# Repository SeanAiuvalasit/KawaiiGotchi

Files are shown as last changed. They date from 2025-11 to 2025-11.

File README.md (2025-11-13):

## AI usage
This project was programmed with the aid of ChatGPT. Specifically, all of the Arduino code for the ESP32.

## How it works

The Kawaiigotchi is powered via a USB connection from a laptop that outputs 5V. When the ESP32 turns on, there should be no weight placed on the scale as the ESP32 tares the load cell. After the display has shown 0 or -0.1 g, the user can place the water bottle on the plate. The amount of time it takes for the Kawaiigotchi to remind the user to drink water can be adjusted by changing the delay in 
[
bool showHint = (millis() - presentSinceMs >= 20000UL);
]. 
The amount of weight change  that qualifies as enough water can be adjusted by changing the constant in the code. 
[
const float ENOUGH_PER_SIP_ML = 100.0f;
]

## Inspiration

NYU Students made a vape pen with a Tamagotchi that dies if the user stops vaping. We loved the idea of a pet tamagotchi device serving as motivation but, for a healthier cause. After long study sessions in the Student Computing Center where we left with dehydration-induced headaches of our own making, we realized what our solution would be… We decided to design a desk-pal for your water bottle where a tamagotchi reminds you to stay hydrated during study sessions.

 ## What it does

The Kawaiigotchi takes in weight inputs from the Load Cell to detect the presence of a water bottle. After a programmed period of time, the screen text changes to remind the user to drink water. It detects when the bottle has been lifted and waits for the user to set the water bottle down. It then compares the weight of the bottle from before and after it was picked up by the user. If the difference surpasses a threshold, a happy Kawaiigotchi is displayed on the screen, otherwise the Kawaiigotchi will alert the user that they did not drink enough water. Both times it will display the change in weight detected by the load cell on the OLED display.

## How we built it

The first step was developing an idea for our problem. Next we assessed the components needed to build the device that reminds students to drink water. We tested different parts to understand how they would operate in our use case. This led to us replacing a force sensitive resistor with a load cell for weight measurement for increase reliability. After understanding how the individual components worked, we soldered connections for the HX711 load cell amplifier IC and started 3D modelling the scale in OnShape. We used a Bambu Lab A1 Mini with pink PLA filament to print the model of the scale. Then we wired the components on a breadboard and started writing the finalized code. We used a ESP32 Devkit, Adafruit SSD1306 OLED display, 5 kg load cell, and HX711 load cell amplifier to make our device.

## Challenges we ran into

Initially we planned on using a force sensitive resistor to detect the presence of the water bottle and measure a change in the weight of the water bottle. Through testing of the force sensitive resistor, we realized that the FSR resistor was incapable of producing an accurate reading and that the reading would change over the course of the resistor being on due to heat increasing the resistance of the resistor decreased.
We initially planned to display an image of a cat according to the water levels drinking. Unfortunately, we were not able to get the code working within the time frame. In replacement, we stayed with the text reminders. The CAD design for the breadboard holder was not deep enough to hold all the electronic components and wires. This did not cause any technical issues, only the final display was not as clean as intended. Another unseen issue ran into from CAD design was the screw to secure the water bottle scale plate to the load cell. The product does work fine despite the protruding screw, but a water bottle cannot be placed on the center of the device. Counterboring the screws would have led to a more flawless product.

## Accomplishments that we're proud of

We’re proud that we finished with a complete product and that no parts were harmed in the process of creating our Kawaiigotchi. We’re also proud that the Kawaiigotchi is fully functional and that it can even be expanded on in the future, and we are also proud of how we were able to use parts that we’ve never used before and make something out of it.

## What we learned

We learned that your first CAD design won’t always be perfect, and that most of the time it will be faulty in some ways. We learned more about setting up the Arduino IDE and the coding language that it uses. This project was our first time utilizing an OLED display. Although we did not use it to the full extent imagined, we still learned how to display information to the screen. 

## What's next for Kawaiigotchi

If we were going to keep the Kawaiigotchi together, we would first improve the CAD design so all of the parts fit inside the Kawaiigotchi. We could also possibly add more faces and states for the display based on different inputs from the user, and we’d also change to a larger display so that we can print full images of silly faces. It could also become a pomodoro timer that lets the user focus by replacing a phone with a desk-pal for timing. Unfortunately, we have to disassemble our Kawaiigotchi and return all of the parts that we borrowed.

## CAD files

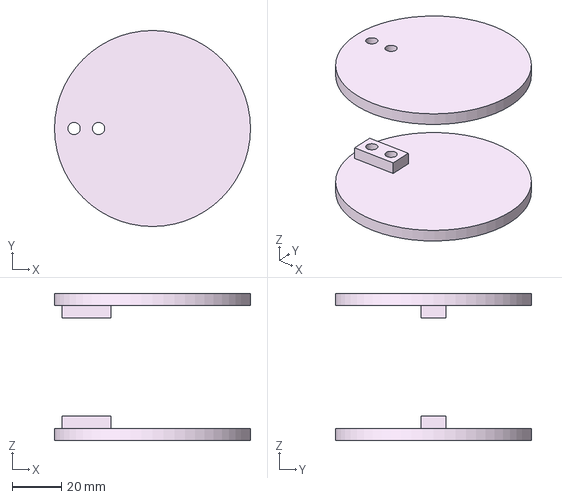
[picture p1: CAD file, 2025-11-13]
Plates.step
80.0 x 80.0 x 60.0 mm

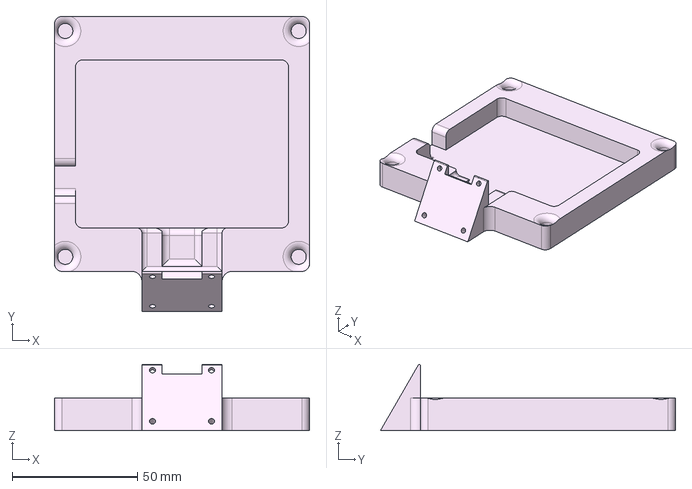
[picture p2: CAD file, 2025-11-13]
Base.step
101.6 x 117.6 x 26.3 mm

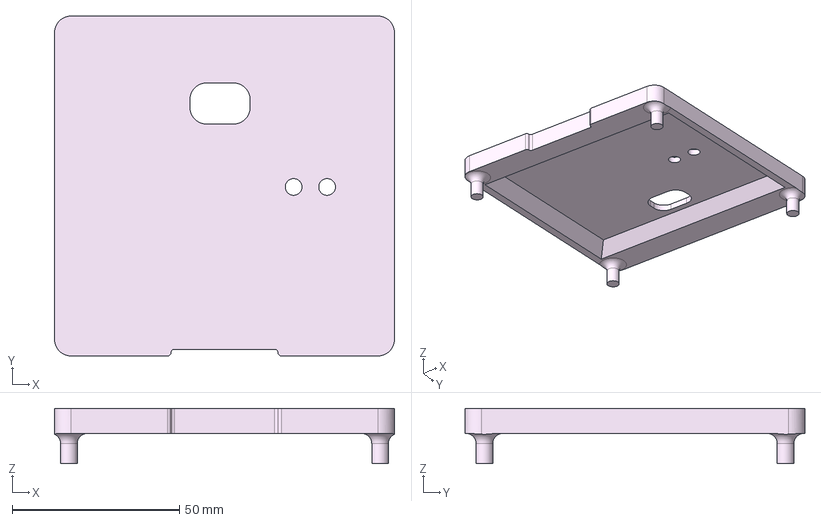
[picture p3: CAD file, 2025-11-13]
Lid.step
101.6 x 101.6 x 16.5 mm

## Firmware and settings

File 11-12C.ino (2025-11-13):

#include <Arduino.h>
#include "HX711.h"
#include <Wire.h>
#include <Adafruit_GFX.h>
#include <Adafruit_SSD1306.h>


// --------- Pins ----------
#define DOUT_PIN    33
#define SCK_PIN     14
#define BUZZER_PIN  27
#define SDA_PIN     22
#define SCL_PIN     21


// --------- Display ----------
#define SCREEN_WIDTH 128
#define SCREEN_HEIGHT 64
Adafruit_SSD1306 display(SCREEN_WIDTH, SCREEN_HEIGHT, &Wire, -1);


// --------- Scale ----------
HX711 scale;
float CAL_FACTOR = 2280.0f;     // adjust after calibration


// --------- Thresholds (grams/mL) ----------
const float THRESHOLD_ON   = 15.0f;     // enter "present" when >= this
const float THRESHOLD_OFF  = 8.0f;      // leave "present" when <= this
const float MIN_SIP        = 5.0f;      // minimum delta to count as a sip
const float STABLE_EPS     = 2.0f;      // small deadband for “stable”
const unsigned long DROP_DEBOUNCE_MS = 1500; // drop must persist this long


// --------- “Enough?” per-sip rule ----------
const float ENOUGH_PER_SIP_ML = 100.0f; // adjust your per-sip target


// --------- State Machine ----------
enum State { NO_BOTTLE, BOTTLE_PRESENT };
State state = NO_BOTTLE;


// --------- Baselines / detection helpers ----------
float presentMaxBaseline = 0.0f;  // max stable level while present
float lastStableLevel    = 0.0f;  // last accepted plateau


bool  dropArmed           = false;  // tracking a candidate drop
float dropStartLevel      = 0.0f;
unsigned long dropStartMs = 0;


// remove/return decision uses this
float pendingBeforeRemoval = 0.0f;


// timing for “waiting for sips…” hint
unsigned long presentSinceMs = 0;  // set when bottle becomes present


// --------- Bitmaps (converted from your files, 64x64, 1-bit) ----------
#define KAWAII_W 64
#define KAWAII_H 64


// Happy cat 64x64 (from: epd_bitmap_ (1).bin), 1-bit, row-packed (LSB first)
const unsigned char PROGMEM kawaii_happy[] = {
  0x00, 0x00, 0x00, 0x00, 0x00, 0x00, 0x00, 0x00, 0x00, 0x00, 0x00, 0x00, 0x00, 0x00, 0x00, 0x00,
  0x00, 0x00, 0x00, 0x00, 0x00, 0x00, 0x00, 0x00, 0x00, 0x00, 0x00, 0x00, 0x00, 0x00, 0x00, 0x00,
  0x00, 0x00, 0x00, 0x00, 0x00, 0x00, 0x00, 0x00, 0x00, 0x00, 0x00, 0x00, 0x00, 0x00, 0x00, 0x00,
  0x00, 0x00, 0x00, 0x00, 0x00, 0x00, 0x00, 0x00, 0x00, 0x00, 0x00, 0x00, 0x00, 0x00, 0x00, 0x00,
  0x1E, 0x00, 0x00, 0x00, 0x00, 0x00, 0x00, 0x00, 0x00, 0x00, 0x00, 0x00, 0x00, 0x00, 0x00, 0x78,
  0xFF, 0x03, 0x00, 0x00, 0x00, 0x00, 0x00, 0x00, 0x00, 0x00, 0x00, 0x00, 0x00, 0x00, 0xC0, 0xFF,
  0xFF, 0x3F, 0x00, 0x00, 0x00, 0x00, 0x00, 0x00, 0x00, 0x00, 0x00, 0x00, 0x00, 0xF0, 0xFF, 0xFF,
  0xFF, 0xFF, 0x03, 0x00, 0x00, 0x00, 0x00, 0x00, 0x00, 0x00, 0x00, 0xC0, 0xFF, 0xFF, 0xFF, 0xFF,
  0xFF, 0xFF, 0x1F, 0x00, 0x00, 0x00, 0x00, 0x00, 0x00, 0x00, 0x80, 0xFF, 0xDF, 0xFB, 0xFF, 0xFF,
  0xFF, 0xDF, 0xFF, 0x01, 0x00, 0x00, 0x00, 0x00, 0x00, 0x80, 0xFF, 0x6F, 0xB6, 0xDB, 0xFF, 0xFF,
  0xFF, 0xAD, 0xFD, 0xFF, 0x00, 0x00, 0x00, 0x00, 0x80, 0xFF, 0x7F, 0xB3, 0x6D, 0xB7, 0xDB, 0xFF,
  0x6D, 0xDB, 0xEC, 0xFF, 0x01, 0x00, 0x00, 0x80, 0xFF, 0xBF, 0x59, 0x6F, 0xB6, 0xDB, 0x6E, 0xDB,
  0xB6, 0xB5, 0xF6, 0xFF, 0x01, 0x00, 0x80, 0xFF, 0xDF, 0xCD, 0xDA, 0xB6, 0x6D, 0xDB, 0xB6, 0xB5,
  0x6D, 0xBB, 0xFD, 0x7F, 0x00, 0x80, 0xFF, 0xDF, 0xCC, 0xB6, 0x6D, 0xDB, 0xB6, 0x6D, 0x6B, 0xDB,
  0xB6, 0x6D, 0xFB, 0x7F, 0x80, 0xFF, 0xDF, 0xCC, 0xB6, 0x6D, 0xDB, 0xB6, 0x6D, 0x6B, 0xDB, 0xB6,
  0x6D, 0xBB, 0xFD, 0x7F, 0x80, 0xFF, 0xDF, 0xCD, 0xDA, 0xB6, 0x6D, 0xDB, 0xB6, 0xB5, 0x6D, 0xBB,
  0xF6, 0xFE, 0x7F, 0x80, 0xFF, 0x7F, 0xB3, 0x6D, 0xB7, 0xDB, 0xFF, 0x6D, 0xDB, 0xEC, 0xFF, 0x7F,
  0x80, 0xFF, 0x6F, 0xB6, 0xDB, 0xFF, 0xFF, 0xFF, 0xAD, 0xFD, 0xFF, 0x7F, 0x80, 0xFF, 0xDF, 0xFB,
  0xFF, 0xFF, 0xFF, 0xDF, 0xFF, 0x7D, 0x7F, 0x80, 0xFF, 0xFF, 0xFF, 0xFF, 0xFF, 0x03, 0x00, 0x00,
  0x80, 0xFF, 0x1F, 0x7F, 0x80, 0xFF, 0xFF, 0xFF, 0xFF, 0x03, 0x00, 0x00, 0x80, 0x7F, 0x00, 0x7E,
  0x80, 0x3F, 0xFC, 0xFF, 0xE1, 0x03, 0x18, 0x00, 0x78, 0x00, 0x3E, 0x80, 0x0F, 0xF0, 0x7F, 0x80,
  0x03, 0x18, 0x00, 0x60, 0x00, 0x18, 0x80, 0x07, 0x80, 0x1F, 0x00, 0x00, 0x03, 0x18, 0x00, 0x60,
  0x00, 0x18, 0x80, 0x07, 0x80, 0x1F, 0x00, 0x00, 0x03, 0x18, 0x00, 0x60, 0x00, 0x18, 0x80, 0x07,
  0x80, 0x1F, 0x00, 0x00, 0x03, 0x18, 0x00, 0x60, 0x00, 0x18, 0x80, 0x0F, 0xF0, 0x7F, 0x80, 0x03,
  0x18, 0x00, 0x60, 0x00, 0x18, 0x80, 0x3F, 0xFC, 0xFF, 0xE1, 0x03, 0x18, 0x00, 0x78, 0x00, 0x3E,
  0x80, 0x7F, 0x00, 0x7E, 0x80, 0xFF, 0x1F, 0x7F, 0x80, 0xFF, 0x03, 0x00, 0x80, 0xFF, 0xFF, 0xFF,
  0xFF, 0x7F, 0x80, 0xFF, 0x7D, 0x7F, 0x80, 0xFF, 0x6F, 0xB6, 0xDB, 0xFF, 0xFF, 0xFF, 0xAD, 0xFD,
  0xFF, 0x7F, 0x80, 0xFF, 0x7F, 0xB3, 0x6D, 0xB7, 0xDB, 0xFF, 0x6D, 0xDB, 0xEC, 0xFF, 0x7F, 0x80,
  0xFF, 0xDF, 0xCD, 0xDA, 0xB6, 0x6D, 0xDB, 0xB6, 0xB5, 0x6D, 0xBB, 0xF6, 0xFE, 0x7F, 0x80, 0xFF,
  0xDF, 0xCC, 0xB6, 0x6D, 0xDB, 0xB6, 0x6D, 0x6B, 0xDB, 0xB6, 0x6D, 0xBB, 0xFD, 0x7F, 0x80, 0xFF,
  0xDF, 0xCC, 0xB6, 0x6D, 0xDB, 0xB6, 0x6D, 0x6B, 0xDB, 0xB6, 0x6D, 0xBB, 0xFD, 0x7F, 0x00, 0x80,
  0xFF, 0xDF, 0xCD, 0xDA, 0xB6, 0x6D, 0xDB, 0xB6, 0xB5, 0x6D, 0xBB, 0xFD, 0x7F, 0x00, 0x80, 0xFF,
  0x7F, 0xB3, 0x6D, 0xB7, 0xDB, 0xFF, 0x6D, 0xDB, 0xEC, 0xFF, 0x7F, 0x00, 0x80, 0xFF, 0x6F, 0xB6,
  0xDB, 0xFF, 0xFF, 0xFF, 0xAD, 0xFD, 0xFF, 0x7F, 0x00, 0x80, 0xFF, 0xDF, 0xFB, 0xFF, 0xFF, 0xFF,
  0xDF, 0xFF, 0x7D, 0x7F, 0x00, 0x80, 0xFF, 0xFF, 0xFF, 0xFF, 0xFF, 0x03, 0x00, 0x00, 0x80, 0xFF,
  0x1F, 0x7F, 0x00, 0xF0, 0xFF, 0xFF, 0x0F, 0x00, 0x80, 0x3F, 0xFE, 0x3F, 0x00, 0xC0, 0xFF, 0xFF,
  0x03, 0x00, 0x80, 0x07, 0xF0, 0x07, 0x00, 0x00, 0xFE, 0x7F, 0x00, 0x00, 0x80, 0x07, 0xF0, 0x07,
  0x00, 0x00, 0xFE, 0x7F, 0x00, 0x00, 0x80, 0x07, 0xF0, 0x07, 0x00, 0xC0, 0xFF, 0xFF, 0x03, 0x00,
  0x80, 0x3F, 0xFE, 0x3F, 0x00, 0xF0, 0xFF, 0xFF, 0x0F, 0x00, 0x80, 0xFF, 0x1F, 0x7F, 0x00, 0xFC,
  0xFF, 0xFF, 0x3F, 0x00
};


// Disappointed face 64x64 (from: epd_bitmap_ (2).bin), 1-bit, row-packed (LSB first)
const unsigned char PROGMEM kawaii_disappointed[] = {
  0x00, 0x00, 0x00, 0x00, 0x00, 0x00, 0x00, 0x00, 0x00, 0x00, 0x00, 0x00, 0x00, 0x00, 0x00, 0x00,
  0x1F, 0x00, 0x00, 0x00, 0x00, 0x00, 0x00, 0x00, 0x00, 0x00, 0x00, 0x00, 0x00, 0x00, 0x80, 0xF7,
  0xFF, 0x01, 0x00, 0x00, 0x00, 0x00, 0x00, 0x00, 0x00, 0x00, 0x00, 0x00, 0x00, 0xF0, 0x3F, 0xFF,
  0xFF, 0x7F, 0x00, 0x00, 0x00, 0x00, 0x00, 0x00, 0x00, 0x00, 0xC0, 0xBF, 0xC9, 0xBE, 0xFF, 0xFE,
  0x0F, 0x00, 0x00, 0x00, 0x00, 0x00, 0x00, 0x80, 0x7F, 0x93, 0x24, 0x69, 0xDE, 0xF7, 0xFD, 0x01,
  0x00, 0x00, 0x00, 0x00, 0x80, 0x7F, 0x93, 0x24, 0x49, 0x92, 0xB4, 0xDE, 0xFB, 0x03, 0x00, 0x00,
  0x00, 0x80, 0x3F, 0x49, 0x92, 0x24, 0x49, 0x92, 0xA4, 0xF5, 0xFE, 0x07, 0x00, 0x00, 0x80, 0x3F,
  0x49, 0x92, 0x24, 0x49, 0x92, 0x24, 0x49, 0xEA, 0xFD, 0x0F, 0x00, 0x00, 0x80, 0x1F, 0x49, 0x92,
  0x24, 0x49, 0x92, 0x24, 0x49, 0x92, 0xF4, 0xFF, 0x1F, 0x00, 0x00, 0xC0, 0x8F, 0x24, 0x49, 0x92,
  0x24, 0x49, 0x92, 0x24, 0x49, 0xEA, 0xFF, 0x3F, 0x00, 0x00, 0xE0, 0x47, 0x92, 0x24, 0x49, 0x92,
  0x24, 0x49, 0x92, 0x24, 0x49, 0xFA, 0xFF, 0x7F, 0x00, 0x00, 0xF0, 0x23, 0x49, 0x92, 0x24, 0x49,
  0x92, 0x24, 0x49, 0x92, 0xA4, 0xFD, 0xFF, 0xFF, 0x00, 0x00, 0xF8, 0x91, 0x24, 0x49, 0x92, 0x24,
  0x49, 0x92, 0x24, 0x49, 0xDA, 0xFF, 0xFF, 0xFF, 0x01, 0x00, 0xFC, 0x48, 0x92, 0x24, 0x49, 0x92,
  0x24, 0x49, 0x92, 0xA4, 0xED, 0xFF, 0xFF, 0xFF, 0x03, 0x00, 0x3E, 0x24, 0x49, 0x92, 0x24, 0x49,
  0x92, 0x24, 0x49, 0xD2, 0xFE, 0xFF, 0x7F, 0x7F, 0x07, 0x00, 0x1F, 0x12, 0x49, 0x92, 0x24, 0x49,
  0x92, 0x24, 0x49, 0xFA, 0xF7, 0xFF, 0x6F, 0x2F, 0x0E, 0x80, 0x0F, 0x89, 0x24, 0x49, 0x92, 0x24,
  0x49, 0x92, 0x24, 0x7D, 0xE3, 0xFF, 0xE7, 0xC7, 0x1C, 0xC0, 0x87, 0x44, 0x92, 0x24, 0x49, 0x92,
  0x24, 0x49, 0xD2, 0xBF, 0xC1, 0xFF, 0xF3, 0xC3, 0x39, 0xE0, 0x43, 0x22, 0x49, 0x92, 0x24, 0x49,
  0x92, 0xA4, 0xB4, 0xDF, 0xE0, 0xFF, 0xF9, 0xF1, 0x73, 0xF0, 0x21, 0x11, 0x49, 0x92, 0x24, 0x49,
  0xD2, 0x5E, 0xDA, 0x6F, 0xF0, 0xFF, 0xFC, 0xF8, 0x39, 0xF8, 0x90, 0x88, 0x24, 0x49, 0x92, 0xA4,
  0xB4, 0xD7, 0xF6, 0x37, 0xF8, 0x7F, 0x7E, 0x7C, 0x1E, 0x7C, 0x48, 0x44, 0x92, 0x24, 0x49, 0xDA,
  0x6D, 0x7B, 0x1B, 0x7C, 0x3F, 0x3F, 0x3E, 0x0F, 0x3E, 0x24, 0x22, 0x49, 0x92, 0xB4, 0xD7, 0xF6,
  0x37, 0x7E, 0x9E, 0x9F, 0x9F, 0x07, 0x1F, 0x12, 0x11, 0x49, 0xDA, 0x6D, 0x7B, 0x1B, 0x3F, 0xCF,
  0xCF, 0xCF, 0x03, 0x0F, 0x89, 0x88, 0xA4, 0xBD, 0xB6, 0xBF, 0xF1, 0xF3, 0xFC, 0xFC, 0x3C, 0xF0,
  0x43, 0x44, 0x24, 0xED, 0xB5, 0xFD, 0xCD, 0x9F, 0xE7, 0xE7, 0xE7, 0x81, 0x07, 0x22, 0x22, 0xE9,
  0xB6, 0xBD, 0x8D, 0x9F, 0xE7, 0xE7, 0xE7, 0x81, 0x07, 0x22, 0x22, 0xA9, 0xB7, 0xBD, 0x8D, 0x9F,
  0xE7, 0xE7, 0xE7, 0x81, 0x07, 0x22, 0x22, 0xA9, 0xB7, 0xBD, 0x8D, 0x9F, 0xE7, 0xE7, 0xE7, 0x81,
  0x07, 0x22, 0x22, 0xA9, 0xB7, 0xBD, 0x8D, 0x9F, 0xE7, 0xE7, 0xE7, 0x81, 0x07, 0x22, 0x22, 0xA9,
  0xB7, 0xBD, 0x8D, 0x9F, 0xE7, 0xE7, 0xE7, 0x81, 0x07, 0x22, 0x22, 0xA9, 0xB7, 0xBD, 0x8D, 0x9F,
  0xE7, 0xE7, 0xE7, 0x81, 0x07, 0x22, 0x22, 0xA9, 0xB7, 0xBD, 0x8D, 0x9F, 0xE7, 0xE7, 0xE7, 0x81,
  0x07, 0x22, 0x22, 0xA9, 0xB7, 0xBD, 0x8D, 0x9F, 0xE7, 0xE7, 0xE7, 0x81, 0x0F, 0x11, 0x11, 0x49,
  0xDB, 0x6D, 0x7B, 0x1B, 0x3F, 0xCF, 0xCF, 0xCF, 0x03, 0x1F, 0x12, 0x11, 0x49, 0xB5, 0xD7, 0xF6,
  0x37, 0x7E, 0x9E, 0x9F, 0x9F, 0x07, 0x3E, 0x24, 0x22, 0x49, 0xDA, 0x6D, 0x7B, 0x1B, 0x7C, 0x3F,
  0x3F, 0x3E, 0x0F, 0x7C, 0x48, 0x44, 0x92, 0xB4, 0xD7, 0xF6, 0x37, 0xF8, 0x7F, 0x7E, 0x7C, 0x1E,
  0xF8, 0x90, 0x88, 0x24, 0x69, 0xDA, 0x6F, 0xF0, 0xFF, 0xFC, 0xF8, 0x39, 0xF0, 0x21, 0x11, 0x49,
  0x92, 0xB4, 0xDF, 0xE0, 0xFF, 0xF9, 0xF1, 0x73, 0xE0, 0x43, 0x22, 0x49, 0x92, 0xA4, 0xB4, 0xDF,
  0xC1, 0xFF, 0xF3, 0xC3, 0x39, 0xC0, 0x87, 0x44, 0x92, 0x24, 0x49, 0xDA, 0x6F, 0x83, 0xFF, 0xE7,
  0xC7, 0x1C, 0x80, 0x0F, 0x89, 0x24, 0x49, 0xB2, 0xDF, 0x06, 0xFF, 0xCF, 0x8F, 0x9B, 0x00, 0x1F,
  0x12, 0x49, 0x92, 0x7C, 0xBF, 0x0D, 0xFE, 0x9F, 0x1F, 0x37, 0x01, 0x3E, 0x24, 0x92, 0x24, 0xF9,
  0x7E, 0x1B, 0xFC, 0x3F, 0x3F, 0x6E, 0x02, 0x7C, 0x48, 0x24, 0x49, 0xF2, 0xFD, 0x36, 0xF8, 0x7F,
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
};


// --------- Helpers ----------
void buzz(uint16_t freq, uint16_t durMs) { tone(BUZZER_PIN, freq, durMs); }


void displayLines(const String &l1, const String &l2 = "", const String &l3 = "") {
  display.clearDisplay();
  display.setTextSize(1);
  display.setTextColor(SSD1306_WHITE);


  display.setCursor(0, 0);
  display.println("Kawaiigochi");
  display.drawLine(0, 10, 127, 10, SSD1306_WHITE);


  if (l1.length()) { display.setCursor(0, 18); display.println(l1); }
  if (l2.length()) { display.setCursor(0, 30); display.println(l2); }
  if (l3.length()) { display.setCursor(0, 42); display.println(l3); }


  display.display();
}


// Show weight; optionally include the “Waiting for sips...” hint
void showWeight(float w, bool showWaitingHint) {
  if (showWaitingHint) {
    displayLines(String("Weight: ") + String(w, 1) + " g", "Waiting for sips...");
  } else {
    displayLines(String("Weight: ") + String(w, 1) + " g");
  }
}


// Smoothed reading (grams ≈ mL)
float readWeight() { return scale.get_units(10); }


// When a drink is detected
void onDrink(float amount) {
  bool enough = (amount >= ENOUGH_PER_SIP_ML);


  display.clearDisplay();
  // Center a 64x64 image on a 128x64 screen -> x = 32, y = 0
  if (enough) {
    display.drawBitmap(32, 0, kawaii_happy, KAWAII_W, KAWAII_H, SSD1306_WHITE);
  } else {
    display.drawBitmap(32, 0, kawaii_disappointed, KAWAII_W, KAWAII_H, SSD1306_WHITE);
  }


  // Text near bottom
  display.setTextSize(1);
  display.setTextColor(SSD1306_WHITE);
  display.setCursor(0, 52);
  display.print("Drank: ");
  display.print(amount, 0);
  display.print(" mL  ");
  display.print("Enough: ");
  display.print(enough ? "Yes" : "No");
  display.display();


  buzz(enough ? 1200 : 800, enough ? 150 : 250);
  delay(10000); // keep result for 10 seconds
}


void setup() {
  Serial.begin(115200);
  pinMode(BUZZER_PIN, OUTPUT);


  Wire.begin(SDA_PIN, SCL_PIN);
  Wire.setClock(100000);


  if (!display.begin(SSD1306_SWITCHCAPVCC, 0x3C)) {
    // continue even if display not found
  }
  display.clearDisplay();
  display.display();


  scale.begin(DOUT_PIN, SCK_PIN);
  scale.set_scale(CAL_FACTOR);
  scale.tare();


  displayLines("Hi! I'm Kawaiigochi", "Let's stay hydrated!");
  delay(1200);
}


void loop() {
  float w = readWeight(); // negative is fine


  switch (state) {
    case NO_BOTTLE: {
      // If returning after removal, decide immediately when it reappears
      if (pendingBeforeRemoval > 0.0f && w >= THRESHOLD_ON) {
        float delta = pendingBeforeRemoval - w; // positive = drank while away
        if (delta >= MIN_SIP) onDrink(delta);


        // initialize baselines
        presentMaxBaseline   = w;
        lastStableLevel      = w;
        dropArmed            = false;
        pendingBeforeRemoval = 0.0f;


        // start the 20s window before showing the waiting hint
        presentSinceMs = millis();


        state = BOTTLE_PRESENT;
        showWeight(w, false); // no "Waiting..." yet
        delay(120);
        return;
      }


      // Fresh appearance with no pending decision
      if (w >= THRESHOLD_ON) {
        presentMaxBaseline = w;
        lastStableLevel    = w;
        dropArmed          = false;


        // start the 20s window before showing the waiting hint
        presentSinceMs = millis();


        state = BOTTLE_PRESENT;
        displayLines("Bottle detected!", "Hello!");
        delay(300);
      } else {
        // No bottle present; just show the weight line (no waiting hint)
        showWeight(w, false);
      }
    } break;


    case BOTTLE_PRESENT: {
      // Track the highest stable level while present
      if (w > presentMaxBaseline) presentMaxBaseline = w;


      // Case A: sip without removal (sustained drop)
      float deltaFromStable = lastStableLevel - w;


      if (!dropArmed) {
        if (deltaFromStable >= MIN_SIP) {
          dropArmed      = true;
          dropStartLevel = lastStableLevel;
          dropStartMs    = millis();
        }
      } else {
        if (millis() - dropStartMs >= DROP_DEBOUNCE_MS) {
          float consumed = dropStartLevel - w;
          if (consumed >= MIN_SIP) {
            onDrink(consumed);
            lastStableLevel = w; // new plateau after sip
            // After onDrink, continue normal display rules
          }
          dropArmed = false;
        } else {
          // Cancel if it bounced back
          if (w >= dropStartLevel - STABLE_EPS) dropArmed = false;
        }
      }


      // Allow stable level to creep up between sips
      if (fabs(w - lastStableLevel) > STABLE_EPS && w > lastStableLevel)
        lastStableLevel = w;


      // Case B: bottle removed
      if (w <= THRESHOLD_OFF) {
        pendingBeforeRemoval = presentMaxBaseline; // remember pre-removal level
        state = NO_BOTTLE;
        displayLines("Bottle removed", "See you soon!");
        delay(250);
      } else {
        // Show "Waiting for sips..." only after 20s from placement
        bool showHint = (millis() - presentSinceMs >= 20000UL);
        showWeight(w, showHint);
      }
    } break;
  }


  delay(120);
}

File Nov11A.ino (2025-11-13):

#include <Arduino.h>
#include "HX711.h"
#include <Wire.h>
#include <Adafruit_GFX.h>
#include <Adafruit_SSD1306.h>


// --------- Pins ----------
#define DOUT_PIN    33
#define SCK_PIN     14
#define BUZZER_PIN  27
#define SDA_PIN     22
#define SCL_PIN     21


// --------- Display ----------
#define SCREEN_WIDTH 128
#define SCREEN_HEIGHT 64
Adafruit_SSD1306 display(SCREEN_WIDTH, SCREEN_HEIGHT, &Wire, -1);


// --------- Scale ----------
HX711 scale;
float CAL_FACTOR = 2280.0f;     // adjust after calibration


// --------- Thresholds (grams/mL) ----------
const float THRESHOLD_ON   = 15.0f;  // enter "present" when >= this
const float THRESHOLD_OFF  = 8.0f;   // leave "present" when <= this
const float MIN_SIP        = 5.0f;   // minimum delta to count
const float STABLE_EPS     = 2.0f;   // deadband for “stable”
const unsigned long DROP_DEBOUNCE_MS = 1500; // drop must persist this long


// --------- Goal/Tracking ----------
float dailyGoal   = 500.0f;    // demo goal (mL)
float totalWater  = 0.0f;      // accumulated mL
unsigned long lastReminderMs = 0;
const unsigned long REMINDER_PERIOD_MS = 30UL * 60UL * 1000UL; // 30 min


// --------- State Machine ----------
enum State { NO_BOTTLE, BOTTLE_PRESENT };
State state = NO_BOTTLE;


// --------- Baselines / detection helpers ----------
float presentMaxBaseline = 0.0f;  // max stable level while present
float lastStableLevel    = 0.0f;  // last accepted plateau


bool  dropArmed          = false; // tracking a candidate drop
float dropStartLevel     = 0.0f;
unsigned long dropStartMs = 0;


// For remove→return decision
float pendingBeforeRemoval = 0.0f;


// --------- Helpers ----------
void buzz(uint16_t freq, uint16_t durMs) { tone(BUZZER_PIN, freq, durMs); }


void displayMessage(const String &msg) {
  display.clearDisplay();
  display.setTextSize(1);
  display.setTextColor(SSD1306_WHITE);
  display.setCursor(0, 0);
  display.println("Kawaiigochi");
  display.drawLine(0, 10, 127, 10, SSD1306_WHITE);
  display.setCursor(0, 18);
  display.println(msg);
  display.display();
}


void displayStatus(float w) {
  display.clearDisplay();
  display.setTextSize(1);
  display.setTextColor(SSD1306_WHITE);


  display.setCursor(0, 0);
  display.print("W: ");
  display.print(w, 1);
  display.print(" g");


  display.setCursor(0, 12);
  display.print("Total: ");
  display.print(totalWater, 0);
  display.print("/");
  display.print(dailyGoal, 0);
  display.println(" mL");


  float pct = (dailyGoal > 0) ? (100.0f * totalWater / dailyGoal) : 0.0f;
  display.setCursor(0, 24);
  display.print("Progress: ");
  display.print(pct, 0);
  display.println("%");


  display.setCursor(0, 40);
  if (pct >= 75)      display.println("I'm so happy!");
  else if (pct >= 25) display.println("Keep sipping!");
  else                display.println("I'm sad...");


  display.display();
}


// Smoothed reading (grams ≈ mL)
float readWeight() { return scale.get_units(10); }


// Count a drink
void onDrink(float amount) {
  totalWater += amount;
  displayMessage("Yay! You drank some water!");
  buzz(1000, 150);
  delay(600);
}


void setup() {
  Serial.begin(115200);
  pinMode(BUZZER_PIN, OUTPUT);


  Wire.begin(SDA_PIN, SCL_PIN);
  Wire.setClock(100000);


  if (!display.begin(SSD1306_SWITCHCAPVCC, 0x3C)) {
    // continue even if display not found
  }
  display.clearDisplay();
  display.display();


  scale.begin(DOUT_PIN, SCK_PIN);
  scale.set_scale(CAL_FACTOR);
  scale.tare();


  displayMessage("Hi! I'm Kawaiigochi\nLet's stay hydrated!");
  delay(1500);
}


void loop() {
  float w = readWeight(); // may be negative; that's fine


  switch (state) {
    case NO_BOTTLE: {
      // If we were waiting for a return after removal, decide immediately on reappear
      if (pendingBeforeRemoval > 0.0f && w >= THRESHOLD_ON) {
        float delta = pendingBeforeRemoval - w; // positive = drank
        if (delta >= MIN_SIP) onDrink(delta);


        // Initialize baselines for new present state
        presentMaxBaseline = w;
        lastStableLevel    = w;
        dropArmed          = false;
        pendingBeforeRemoval = 0.0f;
        state = BOTTLE_PRESENT;
        displayStatus(w);
        delay(120);
        return;
      }


      // Fresh appearance with no pending delta
      if (w >= THRESHOLD_ON) {
        presentMaxBaseline = w;
        lastStableLevel    = w;
        dropArmed          = false;
        state = BOTTLE_PRESENT;
        displayMessage("Hello bottle!");
        delay(300);
      }


      displayStatus(w);
    } break;


    case BOTTLE_PRESENT: {
      // Track max stable level while present
      if (w > presentMaxBaseline) presentMaxBaseline = w;


      // -------- Case A: sip without removal (sustained drop) --------
      float deltaFromStable = lastStableLevel - w;


      if (!dropArmed) {
        if (deltaFromStable >= MIN_SIP) {
          dropArmed     = true;
          dropStartLevel = lastStableLevel;
          dropStartMs    = millis();
        }
      } else {
        // Confirm drop has persisted
        if (millis() - dropStartMs >= DROP_DEBOUNCE_MS) {
          float consumed = dropStartLevel - w;
          if (consumed >= MIN_SIP) {
            onDrink(consumed);
            lastStableLevel = w;  // new plateau after the sip
          }
          dropArmed = false;
        } else {
          // Cancel if it bounced back to near the old level
          if (w >= dropStartLevel - STABLE_EPS) dropArmed = false;
        }
      }


      // Allow stable level to creep up slowly between sips
      if (fabs(w - lastStableLevel) > STABLE_EPS && w > lastStableLevel)
        lastStableLevel = w;


      // -------- Case B: bottle removed --------
      if (w <= THRESHOLD_OFF) {
        pendingBeforeRemoval = presentMaxBaseline; // remember pre-removal level
        state = NO_BOTTLE;
        displayMessage("See you soon!");
        delay(250);
      } else {
        displayStatus(w);
      }
    } break;
  }


  // ----- Periodic reminder -----
  if (millis() - lastReminderMs >= REMINDER_PERIOD_MS) {
    float pct = (dailyGoal > 0) ? (100.0f * totalWater / dailyGoal) : 0.0f;
    if (pct < 75.0f) {
      displayMessage("Time to sip!");
      buzz(1500, 250);
      delay(400);
    } else {
      displayMessage("Great job staying hydrated!");
      delay(500);
    }
    lastReminderMs = millis();
  }


  delay(120); // small UI pacing delay
}

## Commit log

2025-11-13 Create Screen_LED_Code.ino
    Our Screen LED Testing Code
2025-11-13 Create 11-I2C Scanning Test Code.ino
    Testing Code from 11/12
2025-11-13 CAD Files of Kawaiigotchi
    [Base.step, Lid.step, Plates.step]
